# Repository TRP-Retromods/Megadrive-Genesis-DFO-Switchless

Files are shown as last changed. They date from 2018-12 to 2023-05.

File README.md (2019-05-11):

# Megadrive-Genesis-DFO-Switchless
This is a twist on classic DFO from Micro where I put a PIC16F630 and the back for the switchless mod. You need D4S code.

# Links for the Programmer and classic DFO:
https://nfggames.com/forum2/index.php?topic=5744.0
https://oshpark.com/profiles/micro

https://circuit-board.de/forum/index.php/Thread/7810-Sega-32X-Switchless-Mod-f%C3%BCr-Mega-Drive-1-und-auch-2/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

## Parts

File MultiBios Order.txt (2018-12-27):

I recommand to put the multibios in this order:

Original --> EU --> JAP --> USA

( Original is when the PIN are lifted or grounded.)

For my Japanese MegaCD here's the command I put in the batch file:

copy /B jp.bin + eu.bin + jp.bin + us.bin JEJU.bin

Then program the output BIN file in a 27C4096

If the order is not working, try to invert the wire on the Eprom.

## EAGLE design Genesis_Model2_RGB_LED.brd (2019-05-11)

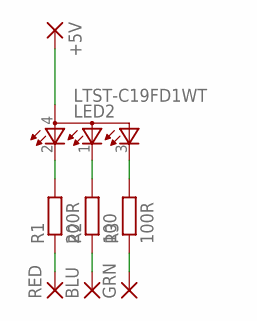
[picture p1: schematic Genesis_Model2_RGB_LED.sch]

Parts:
+5V: SMD2TOP; SMD_SOIC
BLU: SMD2TOP; SMD_SOIC
GRN: SMD2TOP; SMD_SOIC
LED2: LTST-C19FD1WT
R1: 200R; R0805
R2: 100; R0805
R3: 100R; R0805
RED: SMD2TOP; SMD_SOIC

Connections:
unnamed: +5V.1, LED2.4 (A)
unnamed: LED2.2 (CRED), R1.2
unnamed: LED2.1 (CBLUE), R2.2
unnamed: LED2.3 (CGREEN), R3.2
unnamed: R1.1, RED.1
unnamed: BLU.1, R2.1
unnamed: GRN.1, R3.1

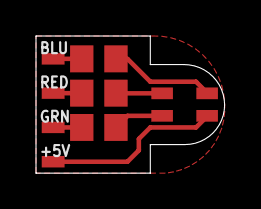
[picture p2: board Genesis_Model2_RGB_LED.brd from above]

Board: 2 copper layers, 10.5 x 7.6 mm, 8 parts (0 on the bottom side), 7 nets.

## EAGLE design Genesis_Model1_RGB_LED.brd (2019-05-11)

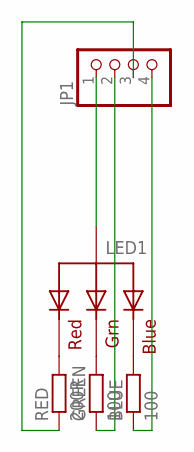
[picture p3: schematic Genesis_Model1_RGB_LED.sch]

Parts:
BLUE: 100; R0805
GREEN: 100; R0805
JP1: PINHD-1X04_2.00; 1X04M
LED1: RGBLED_CA-5MM; LED5MMRGB
RED: 200R; R0805

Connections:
unnamed: LED1.1 (RED), RED.2
unnamed: GREEN.2, LED1.3 (GREEN)
unnamed: BLUE.2, LED1.4 (BLUE)
unnamed: JP1.3, RED.1
unnamed: JP1.1, LED1.2 (VCC)
unnamed: GREEN.1, JP1.2
unnamed: BLUE.1, JP1.4

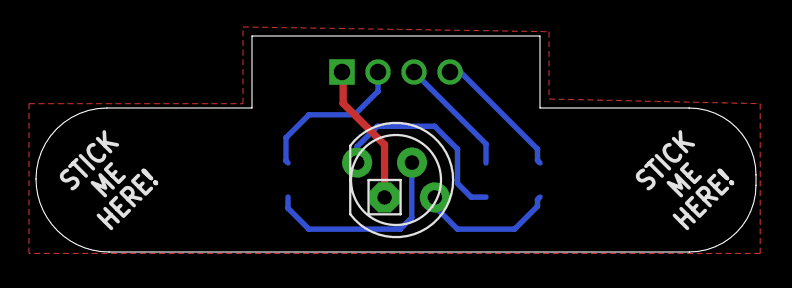
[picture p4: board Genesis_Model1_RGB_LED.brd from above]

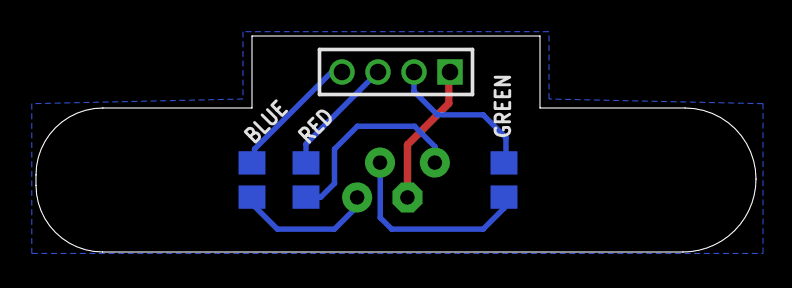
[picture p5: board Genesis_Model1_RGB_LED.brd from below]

Board: 2 copper layers, 40.0 x 12.0 mm, 5 parts (4 on the bottom side), 7 nets.

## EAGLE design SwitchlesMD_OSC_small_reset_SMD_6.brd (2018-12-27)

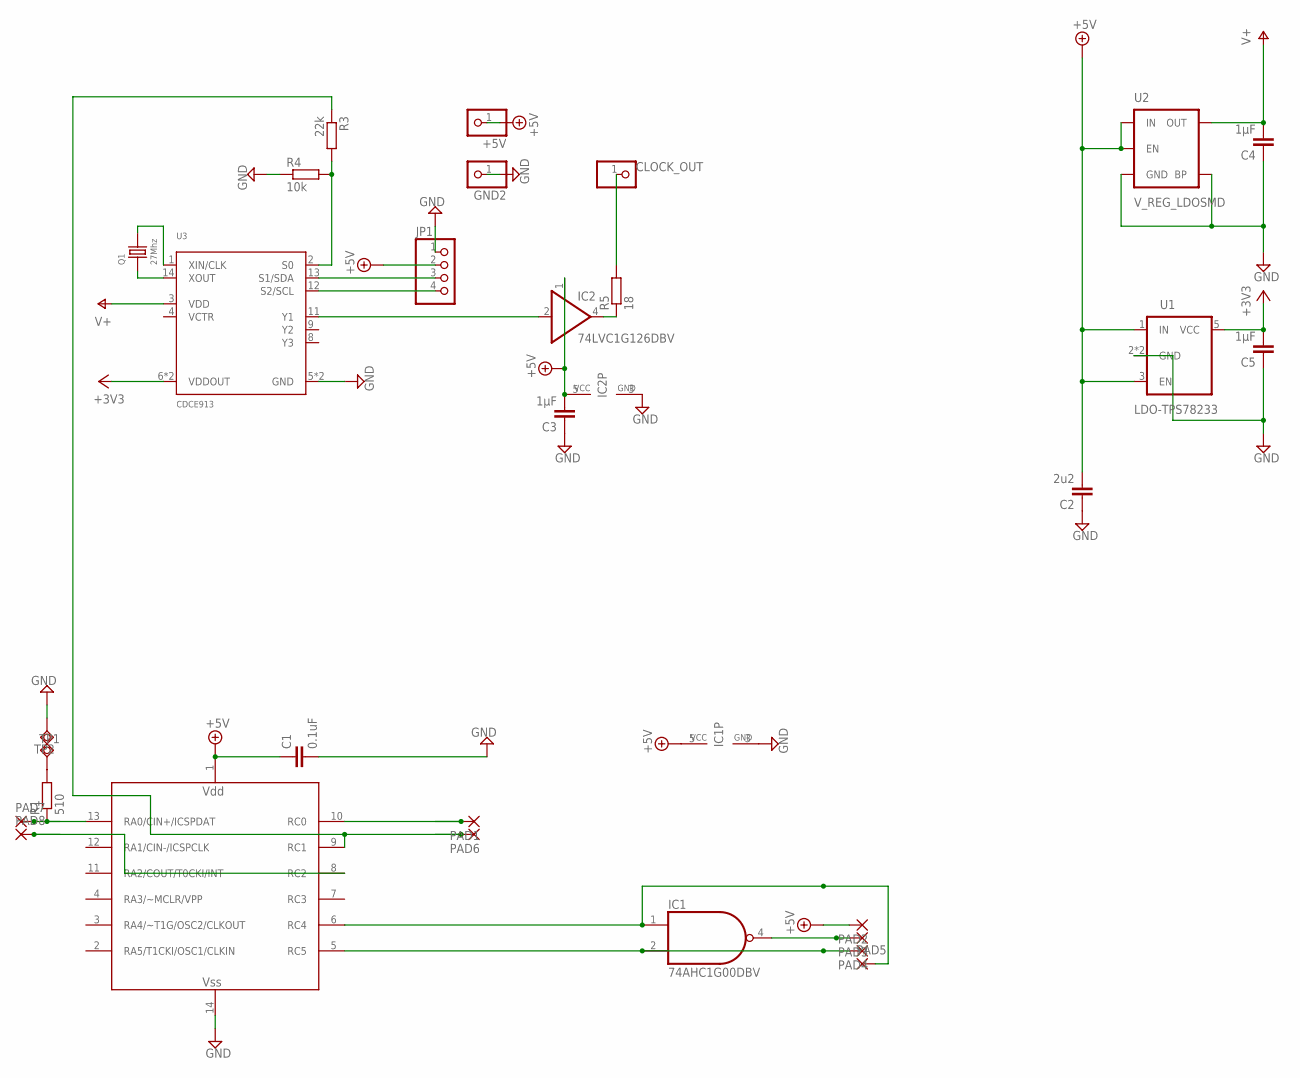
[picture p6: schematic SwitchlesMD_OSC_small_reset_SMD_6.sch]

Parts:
+5V: PINHD-1X01_2.54; 1X01
C1: 0.1uF; C0603
C2: 2u2; C0603
C3, C4, C5: 1µF; C0603
CLOCK_OUT: PINHD-1X01_2.54; 1X01
GND2: PINHD-1X01_2.54; 1X01
IC1: 74AHC1G00DBV; SOT23-5
IC2: 74LVC1G126DBV; SOT23-5
JP1: PINHD-1X04_2.00; 1X04M
PAD1, PAD2, PAD3, PAD4, PAD5, PAD6, PAD7, PAD8: SMD2TOP; SMD_SOIC
PIC16F630: PIC16F630SL; SOIC-14
Q1: 27Mhz; X2-SMD-5.0X3.2X1.3MM
R1: 510; R0603
R3: 22k; R0603
R4: 10k; R0603
R5: 18; R0603
TP1, TP2: TPSQTP07SQ; TP07SQ
U1: LDO-TPS78233; SOT23-5
U2: V_REG_LDOSMD; SOT23-5
U3: CDCE913; TSSOP14

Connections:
+1V8: C4.2, U2.5 (OUT), U3.3 (VDD)
+3V3: C5.2, U1.5 (VCC), U3.6 (VDDOUT), U3.7 (VDDOUT)
+5V: +5V.1, C1.1, C2.2, C3.2, IC1.5 (VCC), IC2.1 (OE), IC2.5 (VCC), JP1.2, PAD2.1, PIC16F630.1 (VDD), U1.1 (IN), U1.3 (EN), U2.1 (IN), U2.3 (EN)
GND: C1.2, C2.1, C3.1, C4.1, C5.1, GND2.1, IC1.3 (GND), IC2.3 (GND), JP1.1, PIC16F630.14 (VSS), R4.1, TP2.TP, U1.2 (GND), U1.4 (GND), U2.2 (GND), U2.4 (BP), U3.5 (GND), U3.10 (GND)
LANG: PAD1.1, PIC16F630.10 (RC0)
LED_EU: IC1.2 (I1), PAD4.1, PIC16F630.5 (RC5)
LED_JP: IC1.1 (I0), PAD5.1, PIC16F630.6 (RC4)
LED_US: IC1.4 (O), PAD3.1
unnamed: R1.2, TP1.TP
unnamed: PAD8.1, PIC16F630.8 (RC2)
unnamed: PAD7.1, PIC16F630.13 (RA0/CIN+/ICSPDAT), R1.1
unnamed: R3.2, R4.2, U3.2 (S0)
unnamed: IC2.4 (O), R5.1
unnamed: CLOCK_OUT.1, R5.2
unnamed: Q1.1, U3.14 (XOUT)
unnamed: Q1.2, U3.1 (XIN/CLK)
unnamed: JP1.3, U3.13 (S1/SDA)
unnamed: JP1.4, U3.12 (S2/SCL)
unnamed: IC2.2 (I), U3.11 (Y1)
VIDEO: PAD6.1, PIC16F630.9 (RC1), R3.1

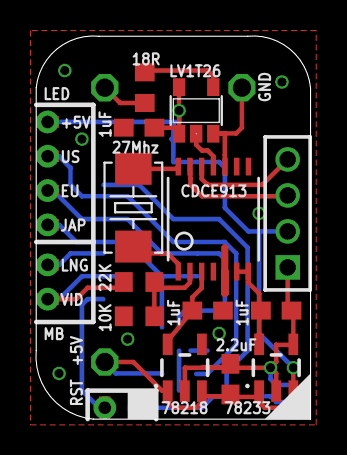
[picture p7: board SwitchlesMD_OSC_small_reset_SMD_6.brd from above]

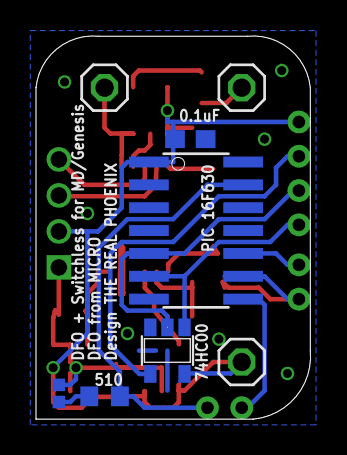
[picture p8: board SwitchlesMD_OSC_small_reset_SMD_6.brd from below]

Board: 2 copper layers, 15.3 x 21.3 mm, 30 parts (9 on the bottom side), 20 nets.

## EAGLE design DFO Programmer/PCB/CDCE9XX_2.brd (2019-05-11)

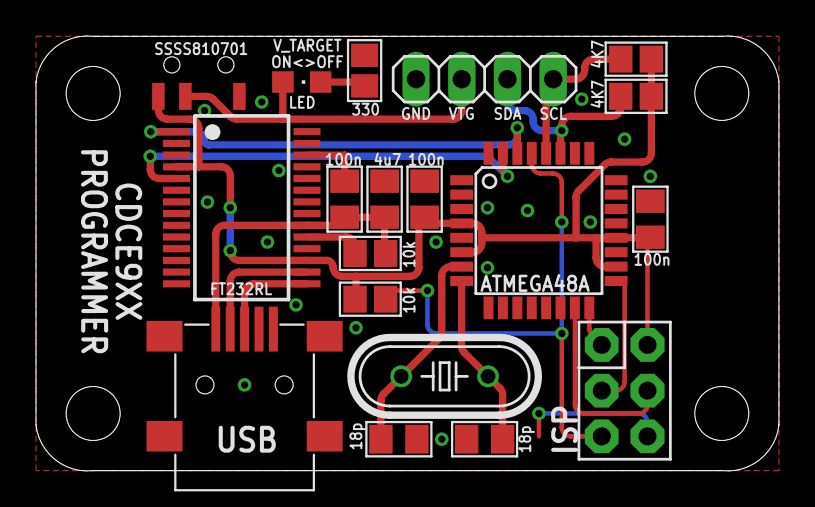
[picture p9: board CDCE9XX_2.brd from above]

Board: 2 copper layers, 41.3 x 24.2 mm, 19 parts (0 on the bottom side), 18 nets.

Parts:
C1, C5, C6: 100n; C0805K_B
C2: 4u7; C0805K_B
C3, C4: 18p; C0805K_B
IC1: FT232RL; SSOP28
IC2: ATMEGA48A; TQFP32-08
JP1: 1X04
LED: CHIPLED_0805
Q1: 10M; HC49/S
R1, R2: 10k; R0805_B
R3, R4: 4K7; R0805_B
R5: 330; R0805_B
U$2: ISPBIG_POGO_PINS; 2X3_ISP_BIGPOGO
U$3: TOGGLE_SWITCH; SSSS810701
USB1: LUMBERG2486_01_MINI_USB_B; LUM2486-01

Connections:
!RESET: IC2.29, R1.2, U$2.RESET
+3V3: C5.2, C6.2, IC1.4, IC1.17, IC2.4, IC2.6, IC2.18, IC2.20, R1.1, R3.2, R4.2, U$2.VCC, U$3.T3
FT_RX: IC1.5, IC2.31
FT_TX: IC1.1, IC2.30
GND: C1.1, C2.1, C3.1, C4.1, C5.1, C6.1, IC1.7, IC1.18, IC1.21, IC1.25, IC1.26, IC2.3, IC2.5, IC2.21, JP1.1, R5.2, U$2.GND, USB1.5GND
unnamed: LED.C, R5.1
unnamed: C1.2, C2.2, IC1.20, R2.2, USB1.1VBUS
unnamed: IC1.19, R2.1
unnamed: C3.2, IC2.7, Q1.2
unnamed: C4.2, IC2.8, Q1.1
unnamed: IC2.16, U$2.MISO
unnamed: IC2.17, U$2.SCK
unnamed: IC2.15, U$2.MOSI
SCL: IC2.28, JP1.4, R4.1
SDA: IC2.27, JP1.3, R3.1
USB+: IC1.15, USB1.3D+
USB-: IC1.16, USB1.2D-
V_TARGET: JP1.2, LED.A, U$3.T2

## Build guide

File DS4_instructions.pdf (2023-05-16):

## Sega Mega Drive/Genesis switchless mod

d4s 2010-10-31 matt@dforce3000.de

Holding reset switch cycles through three available modes indicated by Status LED color:
-50Hz/en (Europe, green)
-60Hz/en (USA, orange)
-60Hz/jp (Japan, red)
Releasing switch sets mode without resetting console.
Triggering reset switch resets console.

Both active-high and active-low reset consoles are supported by sensing the reset line level on startup.
Indicator LED is optional, but strongly recommended.

Tested working on the following pcb versions:
-IC BD M5 PAL VA4 | (PAL early Mega Drive Mk1, active-high reset)
-IC BD M5 PAL | (PAL late Mega Drive Mk1, active-low reset)
-PC BD MD2 VA1.8 PAL (PAL Mega Drive Mk2, active-low reset)

Untested on american, japanese or Mk3 consoles, but should work in theory. Please report your experience with any pcb versions not listed here.

pin configuration:

,-----_-----.
+5V |1 14| GND
|2 A5 A0 13| RESET_IN, /RESET_IN (Reset Button) |3 A4 A1 12|
|4 A3 A2 11|
(red) LED_OUT2 |5 C5 C0 10| LANGUAGE_OUT (en/jp) (grn) LED_OUT1 |6 C4 C1 9| VIDEOMODE_OUT (50/60Hz) |7 C3 C2 8| RESET_OUT, /RESET_OUT (VDP reset line) `-----------'

(/)RESET_IN - Reset Button Input (needs pulldown resistor (5 KOhm) on active-high reset consoles). * LANGUAGE_OUT - English(high)/Japanese(low), JP1/JP2 on Mega Drive Mk1, C65/C68 on Genesis 3. ** VIDEOMODE_OUT - 60Hz(high)/50Hz(low), JP3/JP4 on Mega Drive Mk1, C63/C64 on Genesis 3. **
(/)RESET_OUT - Reset output to videochip. *
LED_OUT1, LED_OUT2 - Use 3-pin dual-color (red/green) LED here. Connect common base of LED to GND via 220 Ohm resistor.

* Cut reset line between reset button and videochip. Be sure to leave pulldown resistor connected to reset button on active-high reset units.
** Make sure to remove/cut any connection on set jumpers. Mk2 consoles don't have any jumpers, you'll have to cut lines here.

If you experience noise problems, you may add a capacitor near the PIC between the +5V and GND lines. I never had any, though.

Parts needed:
-Microchip PIC 16F630
-Some wire
-Dual-color LED | (optional)
-220 Ohm resistor | (optional)
-100nF Ceramic Capacitor | (optional)

Steps required:
-Program supplied hex file to 16F630.
-Solder parts to console PCB according to one of the following diagrams, depending on your PCB version.

Mk1 Mega Drive (IC BD M5 PAL VA4)

Mk1 Mega Drive (IC BD M5 PAL )

Mk2 Mega Drive (PC BD MD2 VA1.8 )

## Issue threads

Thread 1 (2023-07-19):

MD / Genesis Games via Mega Everdrive PRO (by Krikzz) are crashing

BambooShadow, 2023-07-19:
I have a MegaDrive 2 ("MD2 VA0 PAL" mainboard) console with the switchless DFO-mod. It works perfectly well with original cartridges and also with my Mega Everdrive X5.

However, when I use it with the Mega Everdrive PRO, Genesis and Mega Drive Games won't work. They always crash after about 30 seconds of gameplay.
SMS Roms and also Mega CD Games work perfectly fine on that console.

The Mega Everdrive PRO works perfectly well with MD/Genesis Games on an unmodded console.

It is really only the MD/Genesis Roms on the Switchless Console, that are crashing.

Any idea why this happens?

BambooShadow, 2023-07-25:
Here is some gameplay, demonstrating the problems:
1.) game randomly resets (after about 30-60seconds): https://clips.twitch.tv/NeighborlyBoldCaribouFUNgineer-_7I8X7ZQi7jrnDK6
2.) game gets stuck (always seems to be at similar places, but also around 60 seconds after booting the game): https://clips.twitch.tv/LovelyDeadPizzaPMSTwin-uSxKO6tNS-BqzJaD
3.) game randomly crashes (happens sometimes, sometimes not...): https://clips.twitch.tv/DifficultOptimisticPonyRalpherZ-DoRca4VOHG2o83Cp

Some games seem to run fine, without crashing. But most games, show some problems sooner or later. Region doesn't matter, happens to PAL but also NTSC-U & NTSC-J roms.

BambooShadow, 2023-08-16:
@TRP-Retromods this can be closed. After a very extensive analysis, the final solution was absolute prepostorous: re-install the console with the bottom metal/RF-shield included and everything works perfectly fine again! Shouldn't have listened to the 3BP-guide, telling me I could leave out the bottom shield :'-(.

rfmerrill, 2025-10-04:
> [@TRP-Retromods](https://github.com/TRP-Retromods) this can be closed. After a very extensive analysis, the final solution was absolute prepostorous: re-install the console with the bottom metal/RF-shield included and everything works perfectly fine again! Shouldn't have listened to the 3BP-guide, telling me I could leave out the bottom shield :'-(.

I've never heard of this happening. In nearly every scenario the RF shield makes absolutely no difference in functionality.

However, I have observed that the Mega EverDrive Pro drives the data bus very marginally, and on a minority of consoles I had glitchiness and crashes that were solved by removing the capacitor bank CA1 from the data lines (on the console, not the ED), which increased the rise time just enough to make it stable again.

Closed 2023-08-18.

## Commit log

2018-12-27 Add files via upload
    Add Eagle board, and TXT file for Multibios Order.
    [SwitchlesMD_OSC_small_reset_SMD_6.brd, SwitchlesMD_OSC_small_reset_SMD_6.sch]
2019-05-11 Add LEDs PCB
    Add LEDs PCB:
    - DIP for MegaDrive/Genesis Model 1
    - SMD for Model 2
    [DFO_DIPLed.brd, DFO_DIPLed.sch, DFO_SMDLed.brd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]
2019-05-11 adding CDCE9XX PCB
    adding CDCE9XX PCB - Eagle and Gerber file
    [CDCE9XX_2.brd]
2019-05-11 Addind Gerber File for DFO switchless
2020-12-10 Cleaned and organized deposit.
    - Cleaned and organized deposit.
    - Add Firmware/Software for DFO Programmer
    - Add Megadrive/Genesis2 frequency for DFO
    [CDCE9XX_2.brd, Genesis_Model1_RGB_LED.brd, Genesis_Model1_RGB_LED.sch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]

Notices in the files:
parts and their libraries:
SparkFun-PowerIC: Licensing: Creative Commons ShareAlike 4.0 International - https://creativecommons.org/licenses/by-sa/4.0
